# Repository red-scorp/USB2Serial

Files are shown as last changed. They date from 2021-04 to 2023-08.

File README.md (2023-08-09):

```
 __   __  _______  _______  _______  _______  _______  ______    ___   _______  ___     
|  | |  ||       ||  _    ||       ||       ||       ||    _ |  |   | |   _   ||   |    
|  | |  ||  _____|| |_|   ||____   ||  _____||    ___||   | ||  |   | |  |_|  ||   |    
|  |_|  || |_____ |       | ____|  || |_____ |   |___ |   |_||_ |   | |       ||   |    
|       ||_____  ||  _   | | ______||_____  ||    ___||    __  ||   | |       ||   |___ 
|       | _____| || |_|   || |_____  _____| ||   |___ |   |  | ||   | |   _   ||       |
|_______||_______||_______||_______||_______||_______||___|  |_||___| |__| |__||_______|
```

# USB2Serial project

USB to Serial board came as a helping board for my another my project.
I had to program a number of cheap Arduino Pro Mini clone boards in a row.
The problem I was having was to mix up cable all the time.
I decided to fix this issue once and for all by creating a simple USB to Serial interface board which will connect directly with Arduino Pro Mini correctly.

## USB2Serial_CH340G_v1.2

**USB2Serial_CH340G_v1.2** is a simple USB to Serial board based on CH340G chip, created especially to fit well with Arduino Pro Mini boards.

Preview:

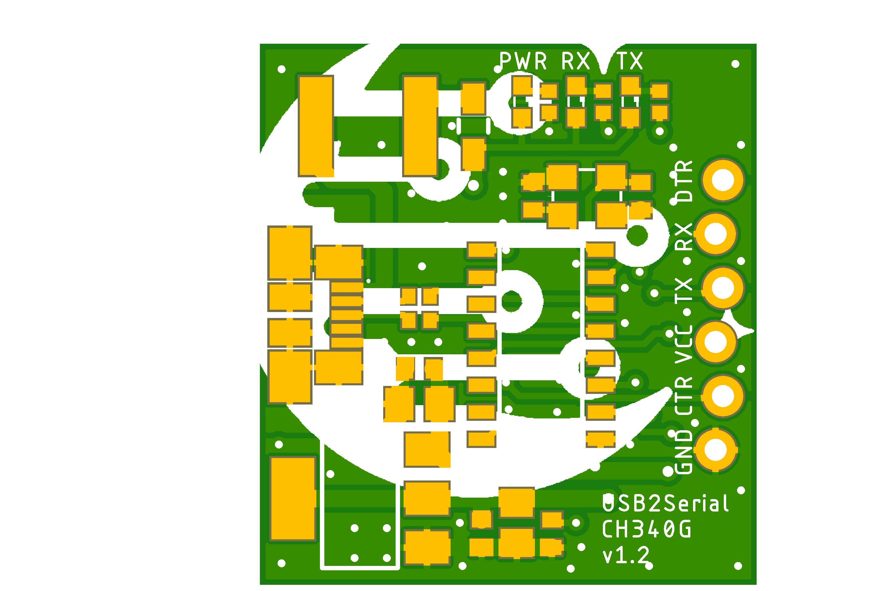
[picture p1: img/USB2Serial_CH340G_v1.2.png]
USB2Serial_CH340G_v1.2 preview


[Schematics in PDF format](doc/USB2Serial_CH340G_v1.2.pdf)

Features:

- based on very cheap CH340G chip
- locked pins for Pro Mini
- configurable for 5V and 3.3V

CAM files are available.
BoM and PnP files for JLCPCB are available.

## USB2Serial_FT232RL_v1.0

**USB2Serial_FT232RL_v1.0** is a simple USB to Serial board based on FT232RL chip, created especially to fit well with Arduino Pro Mini boards.

Preview:

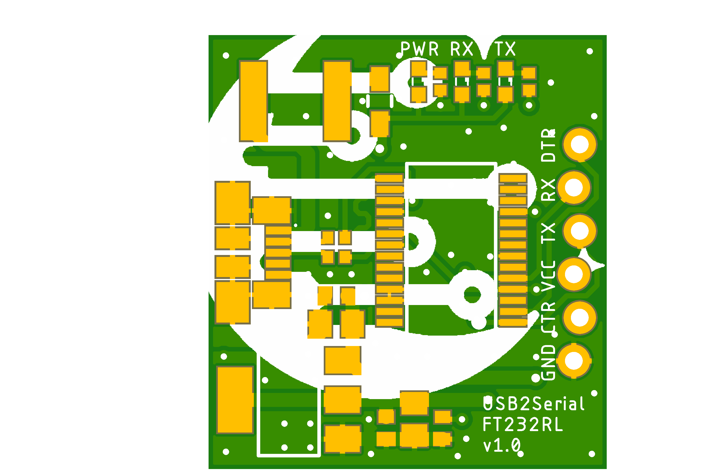
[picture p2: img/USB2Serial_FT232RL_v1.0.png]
USB2Serial_FT232RL_v1.0 preview


[Schematics in PDF format](doc/USB2Serial_FT232RL_v1.0.pdf)

Features:

- based on more common FT232RL chip
- locked pins for Pro Mini
- configurable for 5V and 3.3V

CAM files are available.
BoM and PnP files for JLCPCB are available.

## USB2Serial_CP2102_v1.0

**USB2Serial_CP2102_v1.0** is a simple USB to Serial board based on CP2102 chip, created especially to fit well with Arduino Pro Mini boards.

Preview:

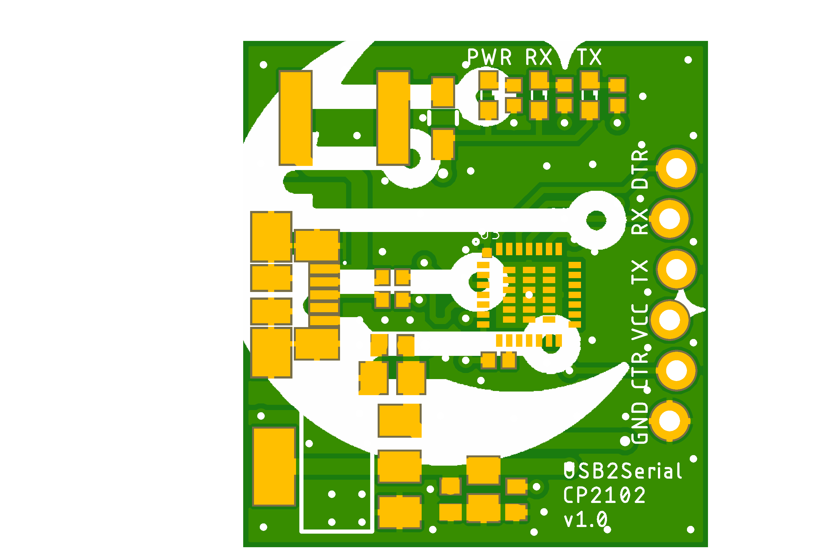
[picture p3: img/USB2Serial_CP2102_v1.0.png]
USB2Serial_CP2102_v1.0 preview


[Schematics in PDF format](doc/USB2Serial_CP2102_v1.0.pdf)

Features:

- based on more common CP2102 chip
- locked pins for Pro Mini
- configurable for 5V and 3.3V

CAM files are available.
BoM and PnP files for JLCPCB are available.

## Links

- CH340G Driver for Windows: [CH341SER_ZIP](http://www.wch.cn/download/CH341SER_ZIP.html)
- FT232RL Driver for Windows: [Home/Drivers/VCP Drivers](https://ftdichip.com/drivers/vcp-drivers/)
- CP2102 Driver for Windows: [CP210x USB to UART Bridge VCP Drivers](https://www.silabs.com/developers/usb-to-uart-bridge-vcp-drivers)

## How to help

Your contributions as code, resources, or finances are welcome! Please contact me directly via email at andriy.golovnya@gmail.com or through my [GitHub profile](https://github.com/red-scorp).

If you'd like to make a financial contribution, you can donate via [PayPal](http://paypal.me/redscorp) or [Ko-Fi](http://ko-fi.com/redscorp). Your support is greatly appreciated.

Thanks in advance!

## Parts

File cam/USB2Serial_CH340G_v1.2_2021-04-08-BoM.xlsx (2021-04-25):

Qty | Designator | Footprint | Comment | LCSC Part #
3 | C5, C6, C7 | 0402 | 100nF | C1525 (https://lcsc.com/product-detail/Multilayer-Ceramic-Capacitors-MLCC-SMD-SMT_SAMSUNG_CL05B104KO5NNNC_100nF-104-10-16V_C1525.html/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)
1 | Q1 | SMD-3225_4P | 12MHz | C9002 (https://lcsc.com/product-detail/SMD-Crystal-Resonators_Yangxing-Tech-X322512MSB4SI_C9002.html/?href=jlc-SMT)
2 | C9, C10 | 0402 | 12pF | C1547 (https://lcsc.com/product-detail/Multilayer-Ceramic-Capacitors-MLCC-SMD-SMT_12pF-120-5-50V_C1547.html/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)
1 | F2 | 1812 | 1812L050/30PR | C883141 (https://lcsc.com/product-detail/PTC-Resettable-Fuses_BHFUSE-BSMD1812-050-30V_C883141.html/?href=jlc-SMT)
3 | R7, R8, R9 | 0402 | 1K | C11702 (https://lcsc.com/product-detail/Chip-Resistor-Surface-Mount_Uniroyal-Elec-0402WGF1001TCE_C11702.html/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)
2 | R1, R2 | 0402 | 22R | C25092 (https://lcsc.com/product-detail/Chip-Resistor-Surface-Mount_Uniroyal-Elec-0402WGF220JTCE_C25092.html/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)
1 | CN2 | MOLEX_47346-0001 | 47346-0001 | n/a
2 | C2, C3 | 0805 | 10uF | C15850 (https://lcsc.com/product-detail/Multilayer-Ceramic-Capacitors-MLCC-SMD-SMT_SAMSUNG_CL21A106KAYNNNE_10uF-106-10-25V_C15850.html/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)
1 | IC1 | SOT-223 | AMS1117-3.3 | C6186 (https://lcsc.com/product-detail/Low-Dropout-Regulators-LDO_AMS_AMS1117-3-3_AMS1117-3-3_C6186.html/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)
2 | LED2, LED3 | LED_0603 | BLUE | C72041 (https://lcsc.com/product-detail/Light-Emitting-Diodes-LED_0603-Blue-light_C72041.html/?href=jlc-SMT)
1 | U1 | SOIC-16_3.9x9.9x1.27P | CH340G | C14267 (https://lcsc.com/product-detail/USB_CH340G_C14267.html/?href=jlc-SMT)
1 | LED1 | LED_0603 | GREEN | C72043 (https://lcsc.com/product-detail/Light-Emitting-Diodes-LED_0603-Green-light_C72043.html/?href=jlc-SMT)
1 | L2 | 0805 | GZ2012D601TF | C1017 (https://lcsc.com/product-detail/Beads_Sunlord-GZ2012D601TF_C1017.html/?href=jlc-SMT)

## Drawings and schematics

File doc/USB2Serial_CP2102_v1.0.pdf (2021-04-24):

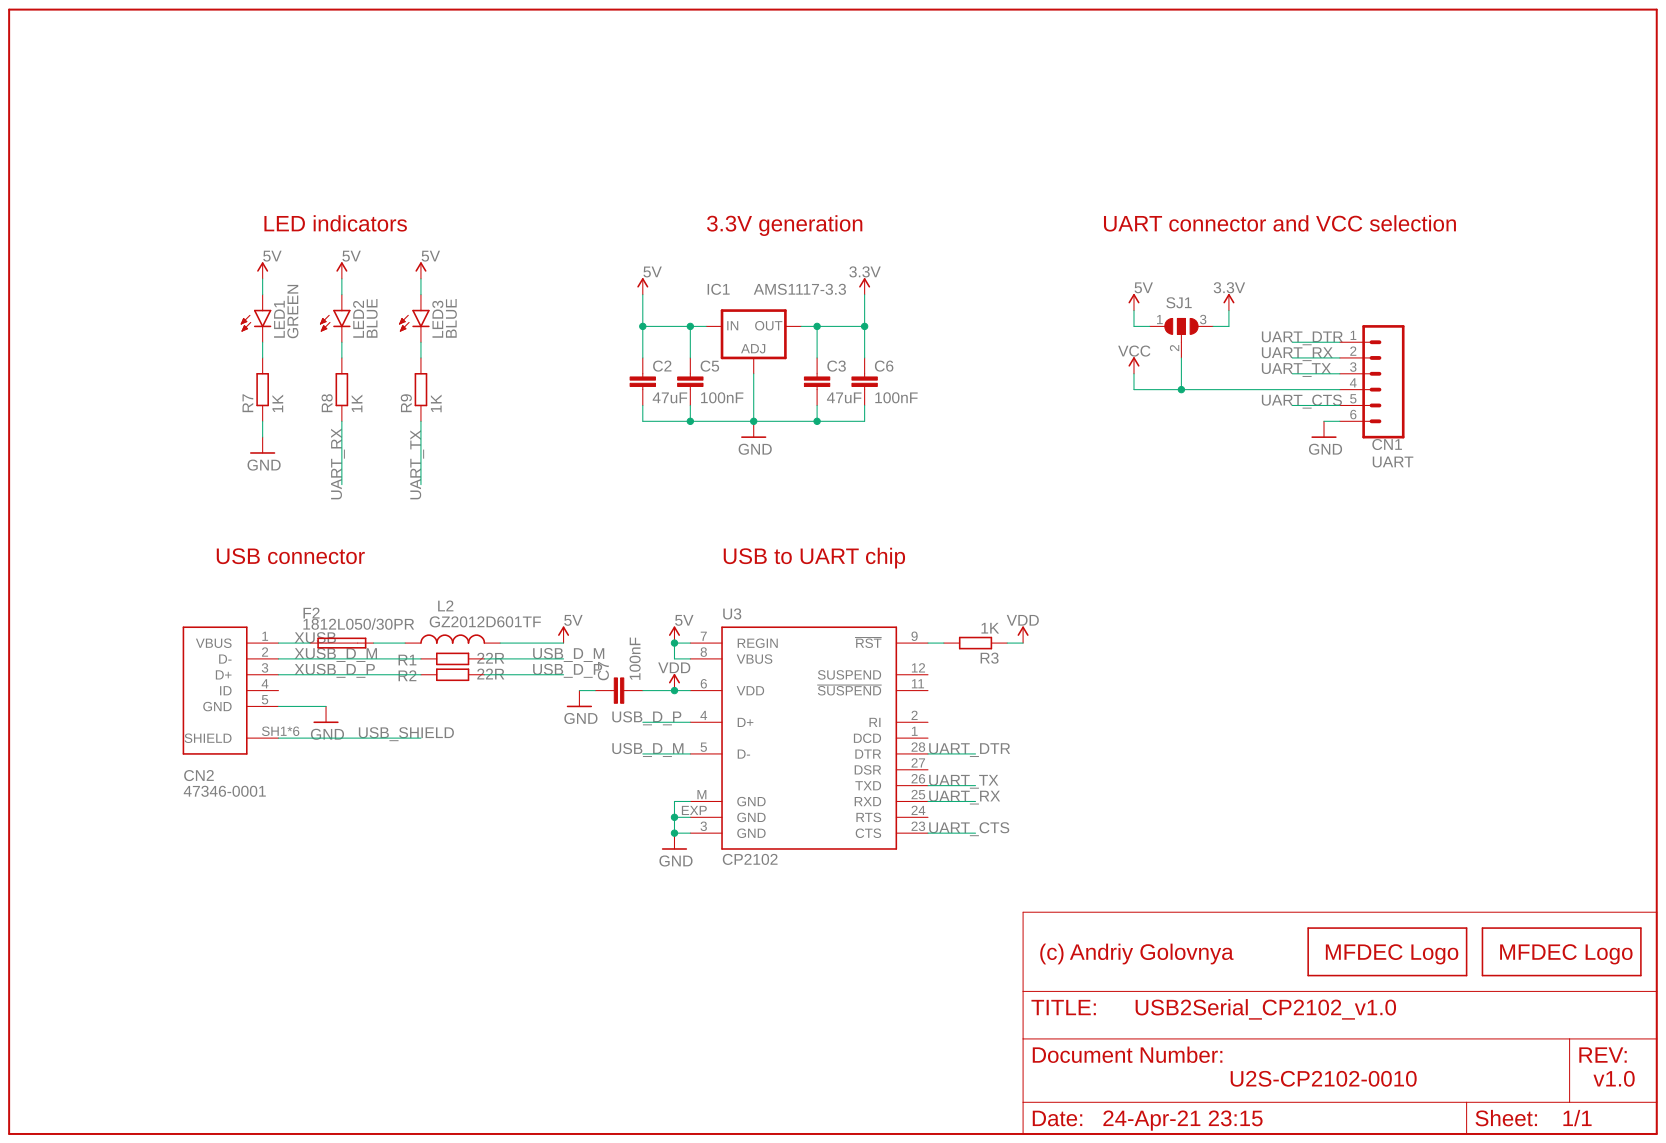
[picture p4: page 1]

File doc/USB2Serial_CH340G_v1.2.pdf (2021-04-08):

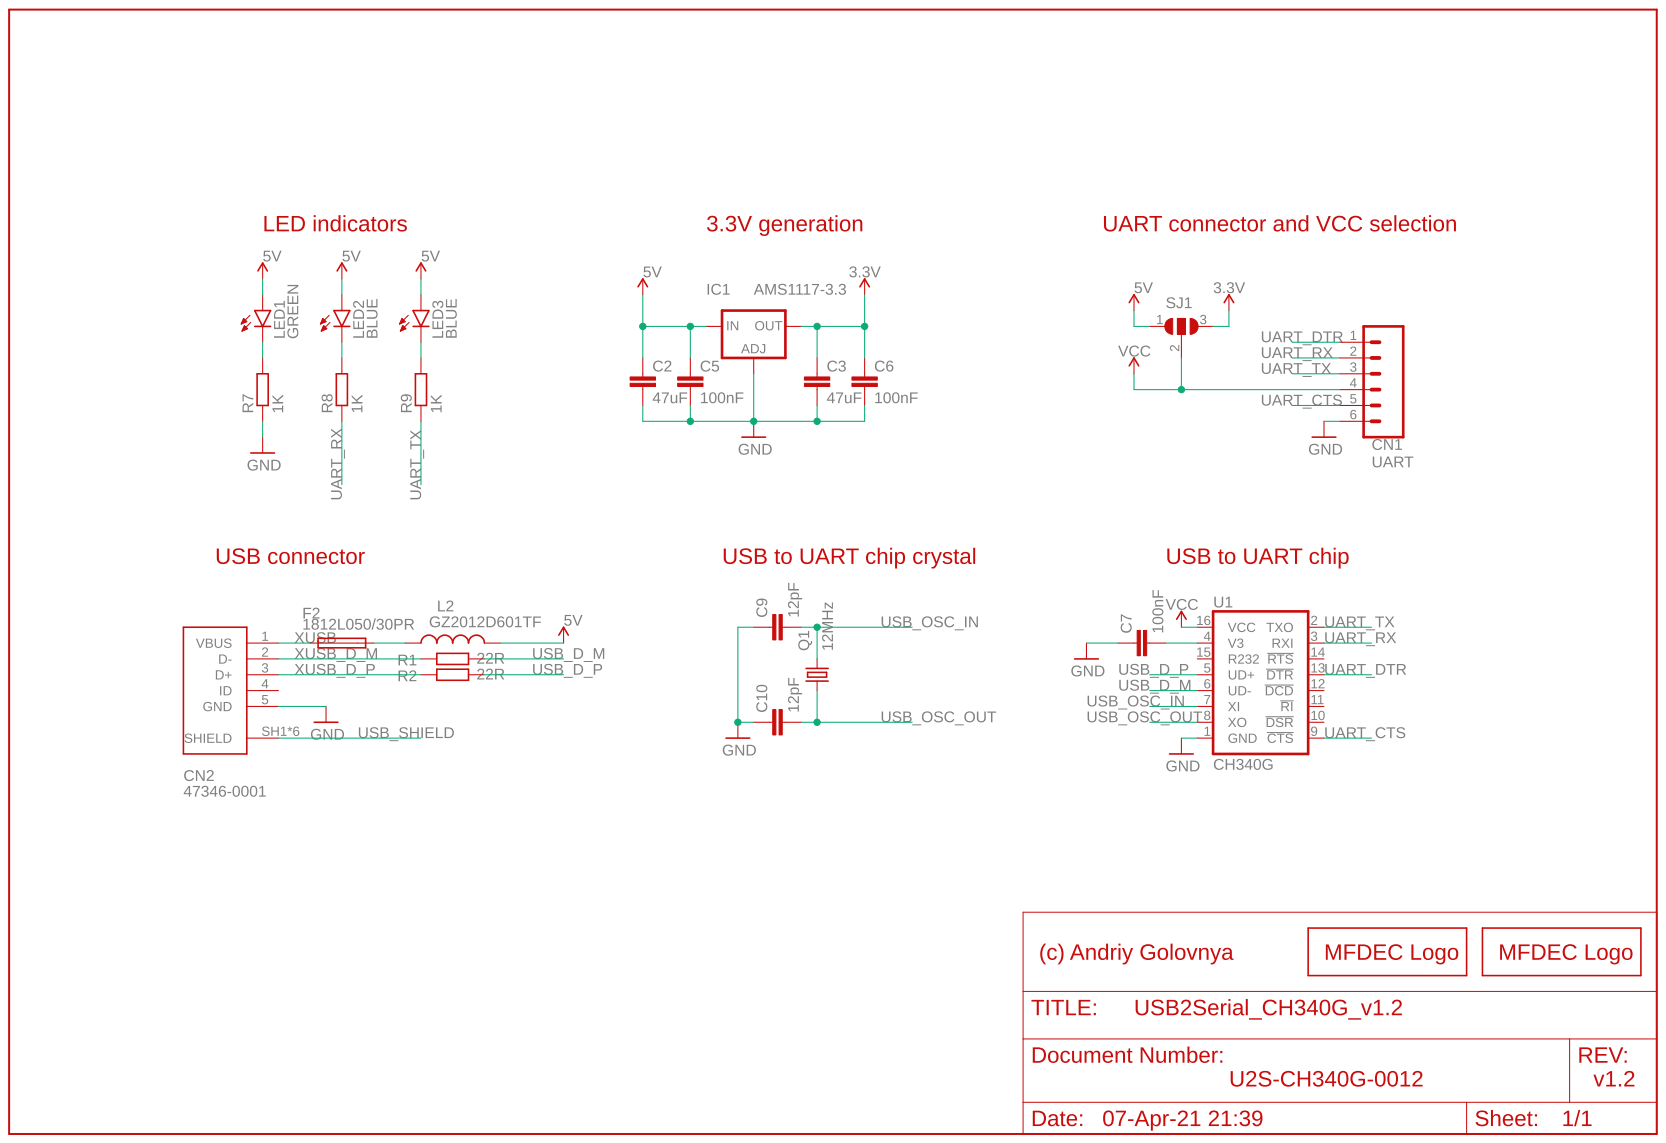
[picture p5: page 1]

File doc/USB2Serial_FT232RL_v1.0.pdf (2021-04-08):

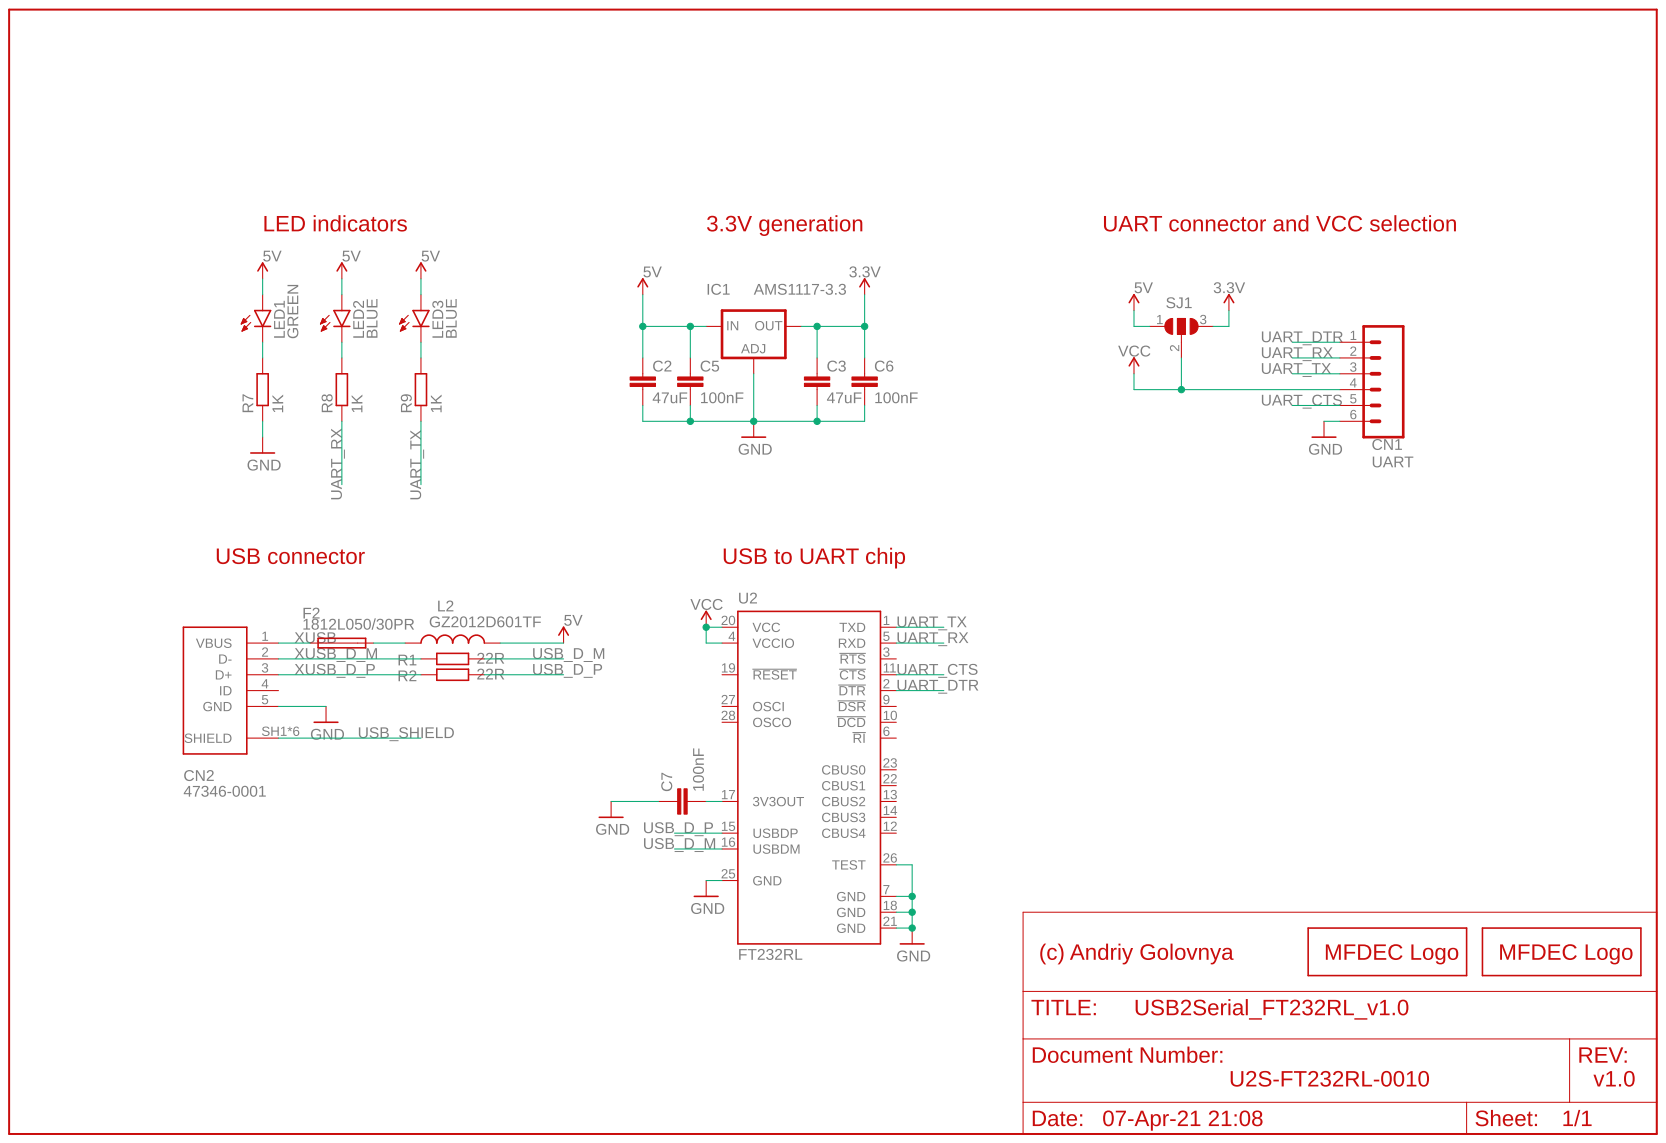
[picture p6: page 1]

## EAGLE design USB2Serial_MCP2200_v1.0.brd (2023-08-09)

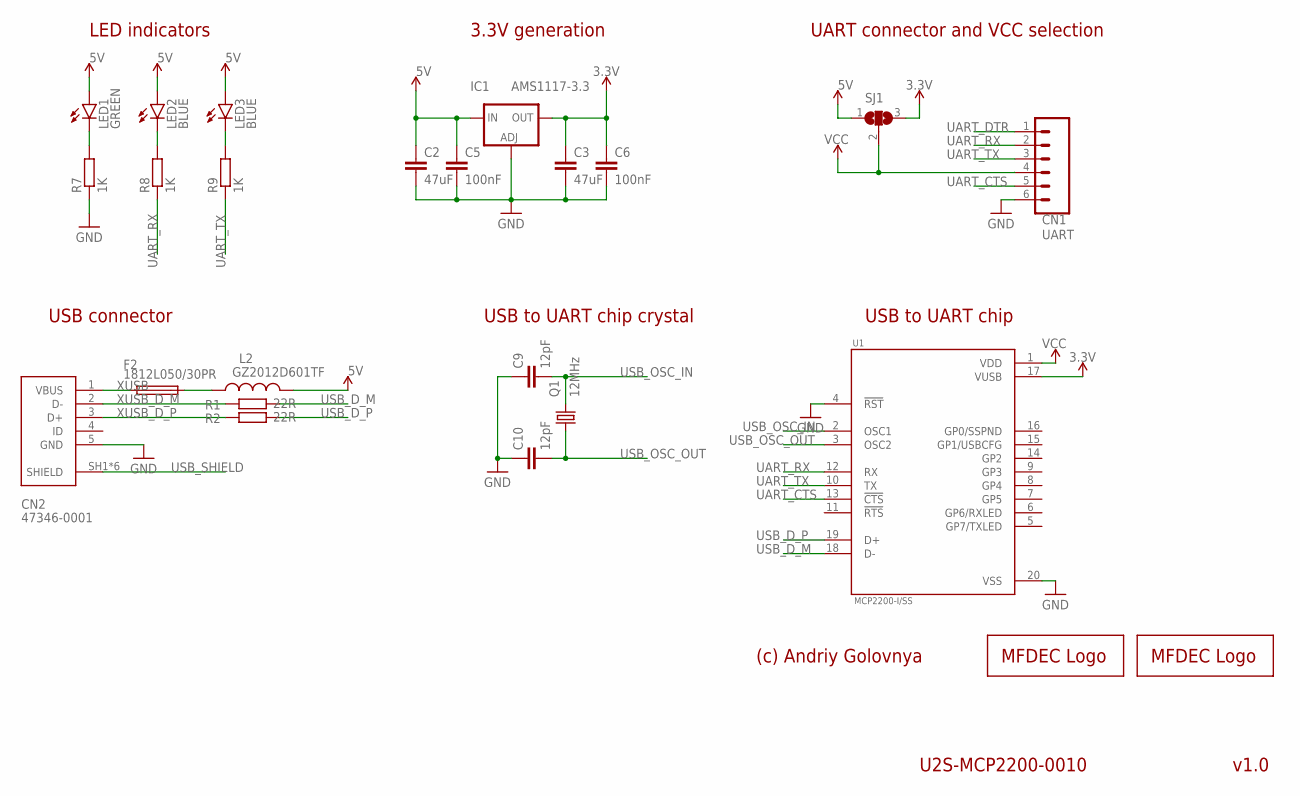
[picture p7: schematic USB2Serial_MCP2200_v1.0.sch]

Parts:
C2, C3: 47uF; C0805
C5, C6: 100nF; C0402
C9, C10: 12pF; C0402
CN1: UART; 1X06_LOCK
CN2: 47346-0001; MOLEX_47346-0001
F2: 1812L050/30PR; MF-SMDF050
IC1: AMS1117-3.3; SOT223
L2: GZ2012D601TF; WE-CBA_0805(W=4)
LED1: GREEN; SML0603
LED2, LED3: BLUE; SML0603
LOGO1: MFDECLOGO_L_20MM; MFDEC_L_20MM
LOGO2: MFDECLOGO_SQ_10MM; MFDEC_SQ_10MM
Q1: 12MHz; 3.2X2.5_KX-7
R1, R2: 22R; R0402
R7, R8, R9: 1K; R0402
SJ1: SJ2FI; SJ_2FI
U1: MCP2200-I/SS; SOP65P780X200-20N

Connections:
3.3V: C3.1, C6.1, IC1.4 (OUT), SJ1.3, U1.17 (VUSB)
5V: C2.1, C5.1, IC1.3 (IN), L2.2, LED1.A, LED2.A, LED3.A, SJ1.1
GND: C2.2, C3.2, C5.2, C6.2, C9.1, C10.1, CN1.6, CN2.5 (GND), IC1.1 (ADJ), R7.1, U1.4 (!RST), U1.20 (VSS)
unnamed: F2.2, L2.1
unnamed: LED1.C, R7.2
unnamed: LED3.C, R9.2
unnamed: LED2.C, R8.2
UART_CTS: CN1.5, U1.13 (!CTS)
UART_DTR: CN1.1
UART_RX: CN1.2, R8.1, U1.12 (RX)
UART_TX: CN1.3, R9.1, U1.10 (TX)
USB_D_M: R1.2, U1.18 (D-)
USB_D_P: R2.2, U1.19 (D+)
USB_OSC_IN: C9.2, Q1.3 (2), U1.2 (OSC1)
USB_OSC_OUT: C10.2, Q1.1, U1.3 (OSC2)
USB_SHIELD: CN2.SH1 (SHIELD), CN2.SH2 (SHIELD), CN2.SH3 (SHIELD), CN2.SH4 (SHIELD), CN2.SH5 (SHIELD), CN2.SH6 (SHIELD)
VCC: CN1.4, SJ1.2, U1.1 (VDD)
XUSB: CN2.1 (VBUS), F2.1
XUSB_D_M: CN2.2 (D-), R1.1
XUSB_D_P: CN2.3 (D+), R2.1

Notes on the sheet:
USB connector
USB to UART chip
USB to UART chip crystal
v1.0
3.3V generation
LED indicators
UART connector and VCC selection
(c) Andriy Golovnya
U2S-MCP2200-0010

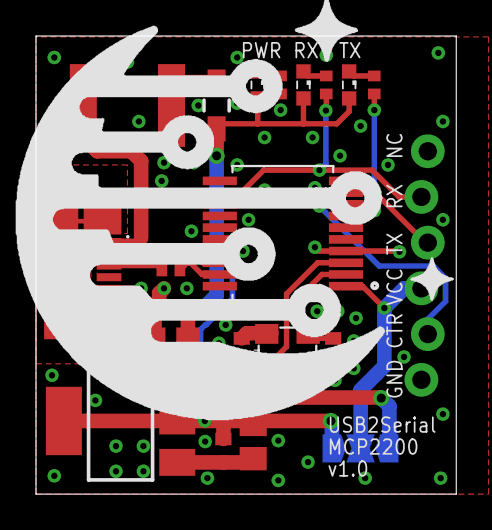
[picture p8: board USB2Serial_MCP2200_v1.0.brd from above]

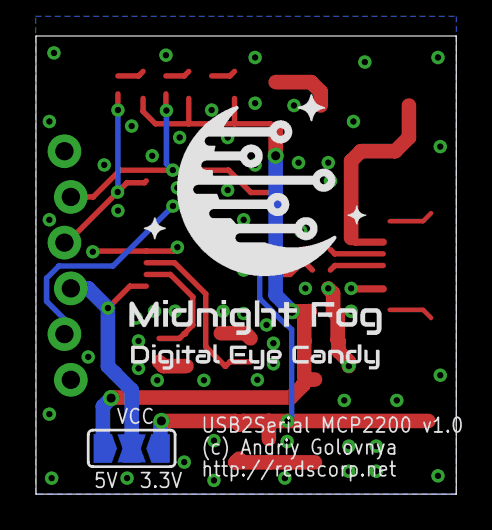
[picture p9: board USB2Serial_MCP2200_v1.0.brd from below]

Board: 2 copper layers, 23.3 x 25.5 mm, 24 parts (2 on the bottom side), 19 nets.

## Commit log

2020-10-19 Add initial design of USB2Serial based on CH340G
    [USB2Serial-CH340G-v1.0.sch]
2020-10-19 Fix some names
    [USB2Serial-CH340G-v1.0.sch]
2020-10-19 Add basic board design. Remove R3 as not strictly needed.
    [USB2Serial-CH340G-v1.0.brd, USB2Serial-CH340G-v1.0.sch]
2020-10-20 Route the board. Add texts and logos
    [USB2Serial-CH340G-v1.0.brd, USB2Serial-CH340G-v1.0.sch]
2020-10-20 Renamed files to keep a common naming convention
    [USB2Serial_CH340G_v1.0.brd, USB2Serial_CH340G_v1.0.sch]
2020-10-22 Add JLCPCB Gerber, BOM and P&P files
    [USB2Serial_CH340G_v1.0_2020-10-22-BOM.xlsx, USB2Serial_CH340G_v1.0_2020-10-22-PaP.xlsx]
2020-11-22 Add document number
    [USB2Serial_CH340G_v1.0.sch]
2021-01-21 Fixed column name in BOM.
    [USB2Serial_CH340G_v1.0_2020-10-22-BOM.xlsx]
2021-01-21 Generated PNG preview. Generated PDF schematics.
2021-02-06 USB2Serial_CH340G_v1.1 files are added.
    [USB2Serial_CH340G_v1.1.brd, USB2Serial_CH340G_v1.1.sch]
2021-02-06 Generated PDF schematics. Generated PNG preview image.
2021-02-07 Removed pin headers contour from PCB v1.1. Generated PNG preview.
    [USB2Serial_CH340G_v1.1.brd, USB2Serial_CH340G_v1.1.sch]
2021-04-06 Added FT232RL based board.
    [USB2Serial_FT232RL_v1.0.brd, USB2Serial_FT232RL_v1.0.sch]
2021-04-07 Added C2. Added 1.2 for CH240G board.
    [USB2Serial_CH340G_v1.2.brd, USB2Serial_CH340G_v1.2.sch]
2021-04-07 Minor changes
    [USB2Serial_CH340G_v1.2.brd]
2021-04-08 Added CAM, preview and schematics.
2021-04-09 Minor changes. Generated new CAM.
    [USB2Serial_FT232RL_v1.0.brd]
2021-04-10 Removed older CH340G boards.
    [USB2Serial_CH340G_v1.0.brd, USB2Serial_CH340G_v1.0.sch, USB2Serial_CH340G_v1.0_2020-10-22-BOM.xlsx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]
2021-04-10 Added new BoM and PnP files (not tested yet)
    [USB2Serial_CH340G_v1.2_2021-04-08-BoM.xlsx, USB2Serial_CH340G_v1.2_2021-04-08-PnP.xlsx, USB2Serial_FT232RL_v1.0_2021-04-09-BoM.xlsx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]
2021-04-11 Fixed BOM and PnP files
    [USB2Serial_CH340G_v1.2_2021-04-08-PnP.xlsx, USB2Serial_FT232RL_v1.0_2021-04-09-BoM.xlsx, USB2Serial_FT232RL_v1.0_2021-04-09-PnP.xlsx]
2021-04-23 Added CP2102 board.
    [USB2Serial_CP2102_v1.0.brd, USB2Serial_CP2102_v1.0.sch]
2021-04-24 Moved some traced around
    [USB2Serial_CP2102_v1.0.brd, USB2Serial_CP2102_v1.0.sch]
2021-04-24 Generated PDF schematics. Generated PNG preview.
2021-04-25 Add BoM and PnP files for CP2102 board.
    [USB2Serial_CP2102_v1.0_2021-04-24-BoM.xlsx, USB2Serial_CP2102_v1.0_2021-04-24-PnP.xlsx]
2021-04-25 Fixed BoM and PnP files for CH340G and FT232RL boards.
    [USB2Serial_CH340G_v1.2_2021-04-08-BoM.xlsx, USB2Serial_CH340G_v1.2_2021-04-08-PnP.xlsx, USB2Serial_FT232RL_v1.0_2021-04-09-BoM.xlsx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]
2023-08-09 First attempt to add MCP2200 based board from last year.
    [USB2Serial_MCP2200_v1.0.brd, USB2Serial_MCP2200_v1.0.sch]

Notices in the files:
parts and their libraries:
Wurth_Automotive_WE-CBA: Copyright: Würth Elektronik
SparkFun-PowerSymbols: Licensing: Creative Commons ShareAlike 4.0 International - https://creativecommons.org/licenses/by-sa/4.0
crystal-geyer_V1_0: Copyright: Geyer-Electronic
